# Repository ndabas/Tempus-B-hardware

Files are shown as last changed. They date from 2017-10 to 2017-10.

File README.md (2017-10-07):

# Tempus B - GPS Clock

This project is a simple desk clock, synchronized to GPS using an on-board or external GPS receiver.

An ATtiny85 microcontroller runs the operation. Six 7-segment digits (in two 3-digit modules with colons) display the time. The display is controlled via an HT16K33 driver over I2C.

## Current Status

The hardware works. I got the boards fabricated by Elecrow, and everything looks good. I'm working on finalizing the software (which is currently written using Arduino.)

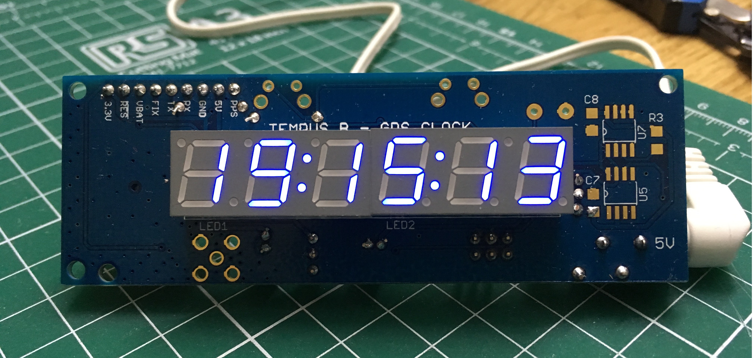
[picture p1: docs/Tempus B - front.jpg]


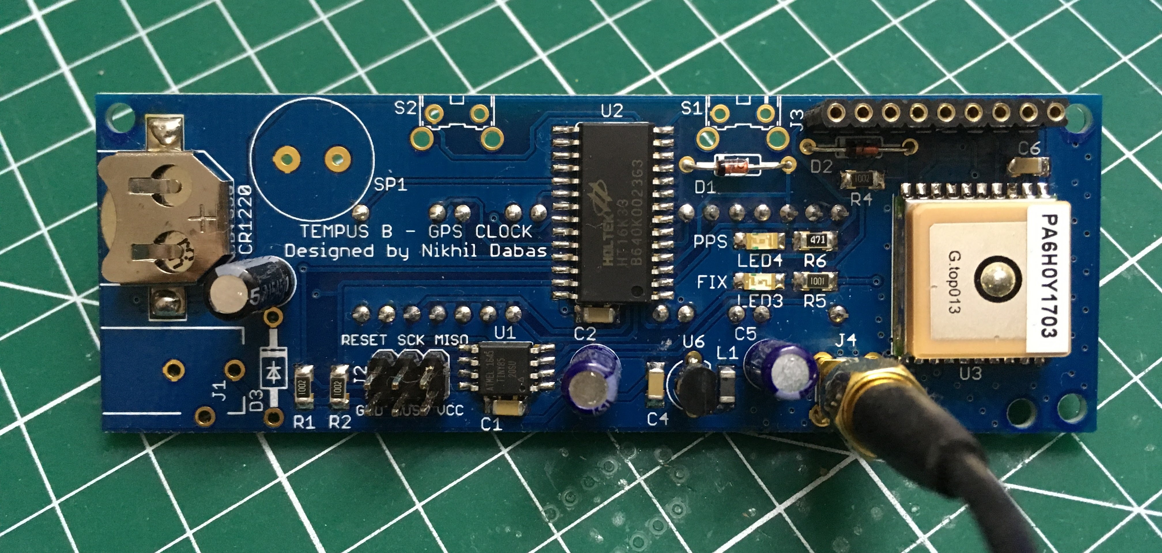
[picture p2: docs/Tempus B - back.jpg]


## Design

I used an ATtiny85 as a challenge in using the smallest possible (both in terms of memory and I/O pins) microcontroller while still maintining a high level of accuracy. The ATtiny has 8K of flash and 512 bytes of RAM. The design uses 5 I/O pins to receive serial data and PPS from the GPS module, and also control the display over I2C. The display controller also has keyscan built-in, so I use that to read two buttons for human interaction. There's also a little piezo speaker on board for beeps and boops.

I've used a mix of through-hole and SMD parts, partly to make construction easy and partly because I used whatever I had lying around.

The board has a footprint for the Global Top PA6H GPS module, as used in the [Adafruit Ultimate GPS v3](https://www.adafruit.com/product/746). There's a pin header as well to plug in the Adafruit board instead; you could use your own GPS module by connecting up the pins there. The board can work with 5V or 3.3V logic. All that's needed is the TX  and the PPS from the GPS module.

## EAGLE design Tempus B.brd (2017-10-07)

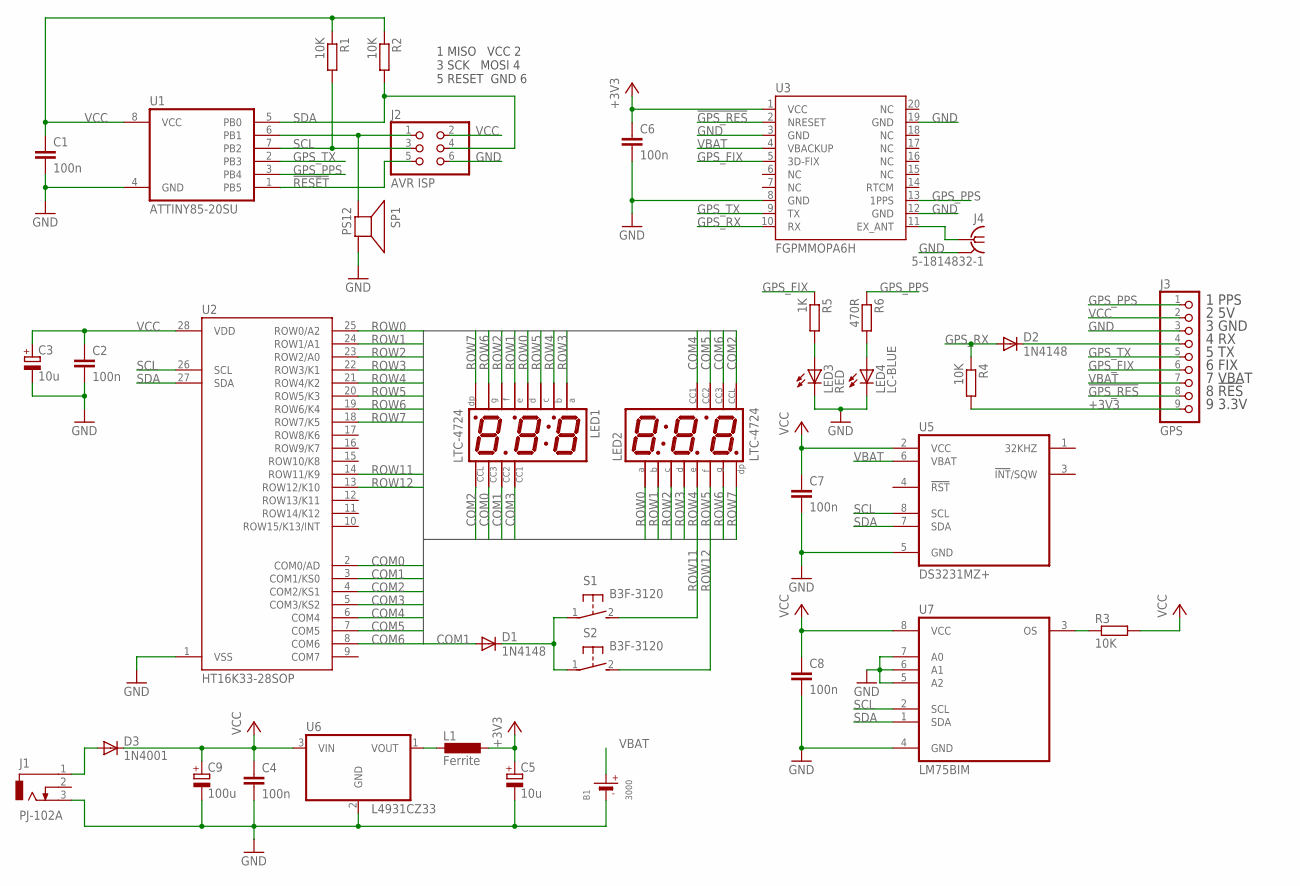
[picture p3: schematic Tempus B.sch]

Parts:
B1: 3000; CR1220
C1, C2, C4, C6, C7, C8: 100n; C1206
C3, C5: 10u; E2-5
C9: 100u; E2-5
D1, D2: 1N4148; DO35-10
D3: 1N4001; DO41-10
J1: PJ-102A; DCJACK-2.0MM
J2: AVR ISP; 2X03
J3: GPS; 1X09
J4: 5-1814832-1; SMA-TH-ST
L1: Ferrite; L3216C
LED1, LED2: LTC-4724; DIL15-LTC-4724
LED3: RED; CHIPLED_1206
LED4: LC-BLUE; CHIPLED_1206
R1, R2, R3, R4: 10K; R1206
R5: 1K; R1206
R6: 470R; R1206
S1, S2: B3F-3120; B3F-31XX
SP1: PS12
U1: ATTINY85-20SU; SO08-EIAJ
U2: HT16K33-28SOP; SO28W
U3: FGPMMOPA6H
U5: DS3231MZ+; SO08
U6: L4931CZ33; TO92-LINE
U7: LM75BIM; SO08

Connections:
!GPS_RES: J3.8, U3.2 (NRESET)
!RESET: J2.5, U1.1 (PB5)
+3V3: C5.+, C6.1, J3.9, L1.1, R4.2, U3.1 (VCC)
COM0: LED1.7 (CC3), U2.2 (COM0/AD)
COM1: D1.A, LED1.5 (CC2), U2.3 (COM1/KS0)
COM2: LED1.14 (CCL), LED2.14 (CCL), U2.4 (COM2/KS1)
COM3: LED1.1 (CC1), U2.5 (COM3/KS2)
COM4: LED2.1 (CC1), U2.6 (COM4)
COM5: LED2.5 (CC2), U2.7 (COM5)
COM6: LED2.7 (CC3), U2.8 (COM6)
GND: B1.-, C1.2, C2.2, C3.-, C4.2, C5.-, C6.2, C7.2, C8.2, C9.-, J1.3, J2.6, J3.3, J4.2, J4.3 (2), J4.4 (2), J4.5 (2), LED3.C, LED4.C, SP1.P$2 (-), U1.4 (GND), U2.1 (VSS), U3.3 (GND), U3.8 (GND), U3.12 (GND), U3.19 (GND), U5.5 (GND), U6.2 (GND), U7.4 (GND), U7.5 (A2), U7.6 (A1), U7.7 (A0)
GPS_FIX: J3.6, R5.1, U3.5 (3D-FIX)
GPS_PPS: J3.1, R6.1, U1.3 (PB4), U3.13 (1PPS)
GPS_RX: D2.A, R4.1, U3.10 (RX)
GPS_TX: J3.5, U1.2 (PB3), U3.9 (TX)
unnamed: D1.C, S1.1, S2.1
unnamed: D3.A, J1.1
unnamed: J2.1, SP1.P$1 (+), U1.6 (PB1)
unnamed: LED3.A, R5.2
unnamed: J4.1, U3.11 (EX_ANT)
unnamed: R3.1, U7.3 (OS)
unnamed: L1.2, U6.1 (VOUT)
unnamed: LED4.A, R6.2
unnamed: D2.C, J3.4
ROW0: LED1.4 (D), LED2.12 (A), U2.25 (ROW0/A2)
ROW1: LED1.2 (E), LED2.11 (B), U2.24 (ROW1/A1)
ROW2: LED1.15 (F), LED2.3 (C), U2.23 (ROW2/A0)
ROW3: LED1.12 (A), LED2.4 (D), U2.22 (ROW3/K1)
ROW4: LED1.11 (B), LED2.2 (E), U2.21 (ROW4/K2)
ROW5: LED1.3 (C), LED2.15 (F), U2.20 (ROW5/K3)
ROW6: LED1.8 (G), LED2.8 (G), U2.19 (ROW6/K4)
ROW7: LED1.6 (DP), LED2.6 (DP), U2.18 (ROW7/K5)
ROW11: S1.2 (S), U2.14 (ROW11/K9)
ROW12: S2.2 (S), U2.13 (ROW12/K10)
SCL: J2.3, R1.2, U1.7 (PB2), U2.26 (SCL), U5.8 (SCL), U7.2 (SCL)
SDA: J2.4, R2.2, U1.5 (PB0), U2.27 (SDA), U5.7 (SDA), U7.1 (SDA)
VBAT: B1.+$1 (+), J3.7, U3.4 (VBACKUP), U5.6 (VBAT)
VCC: C1.1, C2.1, C3.+, C4.1, C7.1, C8.1, C9.+, D3.C, J2.2, J3.2, R1.1, R2.1, R3.2, U1.8 (VCC), U2.28 (VDD), U5.2 (VCC), U6.3 (VIN), U7.8 (VCC)

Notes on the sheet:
1 MISO VCC 2 3 SCK MOSI 4 5 RESET GND 6
1 PPS 2 5V 3 GND 4 RX 5 TX 6 FIX 7 VBAT 8 !RES 9 3.3V

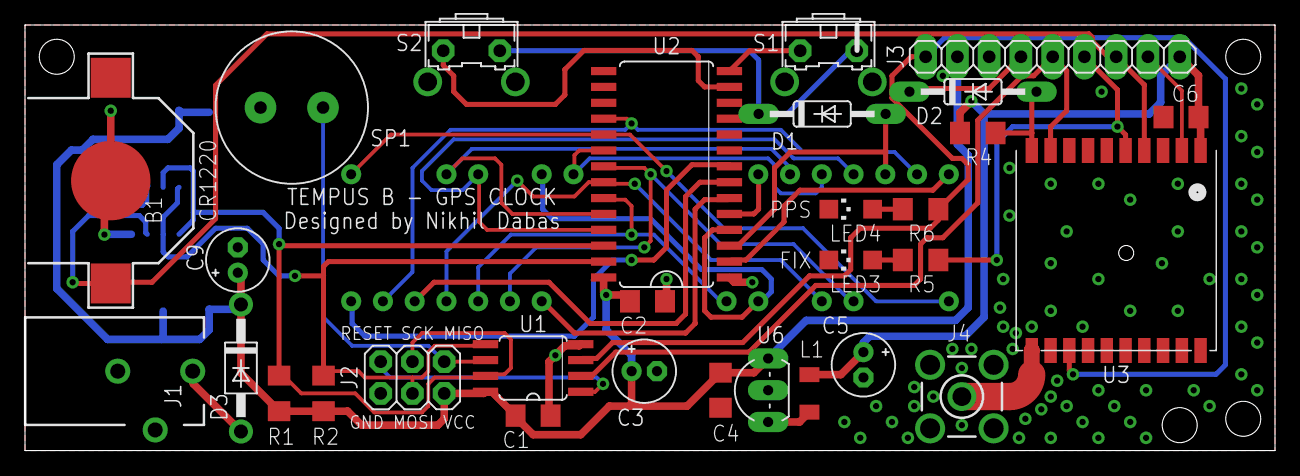
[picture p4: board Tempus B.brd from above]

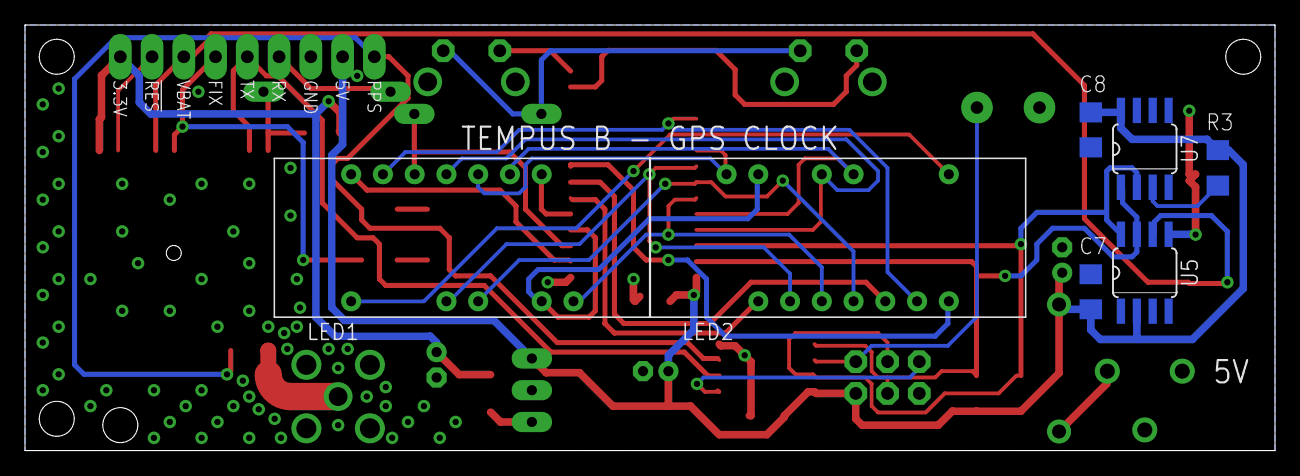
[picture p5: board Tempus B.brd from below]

Board: 2 copper layers, 100.0 x 34.0 mm, 37 parts (7 on the bottom side), 38 nets.

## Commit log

2017-08-21 PCBs sent for fabrication!
    [Tempus B.brd, Tempus B.sch]
2017-10-07 Tweaking LED resistor values
    After testing with the LEDs I ordered, it turns out we need a really
    tiny current (0.5mA to 1mA) for the LEDs.
    [Tempus B.brd, Tempus B.sch]
